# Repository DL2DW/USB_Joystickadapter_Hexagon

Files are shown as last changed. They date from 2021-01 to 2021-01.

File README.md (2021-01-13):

# USB Joystickadapter from Hexagon (SMD Version)

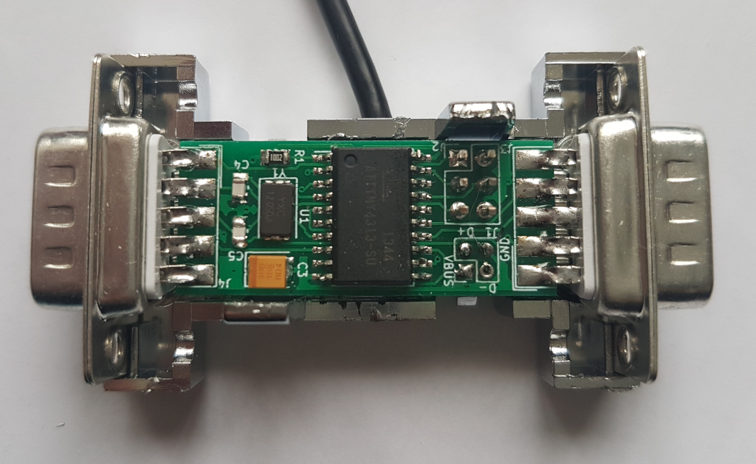
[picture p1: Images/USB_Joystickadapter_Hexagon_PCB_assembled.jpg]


I found the documentation and firmware for this joystick adapter on the website http://www.hexagons.de/index.php/USB_Joystickadapter some time ago. This is no longer available online for a long time.

It is a joystick adapter with 2 ports for the known DB9 connectors, as they are used with the Atari, or Commodore joysticks. 

This adapter can be connected to a PC or the well known MiSTer FPGA hardware, and so the old homecomputer joysticks can be used on modern hardware.

## "Sinchai" version

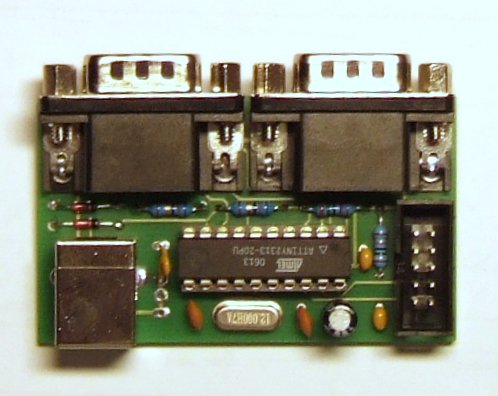
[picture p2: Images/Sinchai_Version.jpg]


There is also a version that is built with normal THT components. This was once sold in a store, but it no longer exists.

And I could not find a suitable case for Hexagon's version. So I packed the hardware into an existing case with the help of a newly developed circuit board.

## Assembly

Under the article number "COM 943" there is a housing at the electronics mail order company Reichelt from Germany ( https://www.reichelt.de/selbstbaugehaeuse-d-sub-2x-9-pol-metallisiert-com-943-p161.html?&nbc=1 ), in which two 9pin D-SUB sockets fit wonderfully. You only have to drill a small hole for the USB cable.

The board is equipped with SMD components to save space. Whereby I have worked here with parts as large as possible, so that on SMD beginners could assemble this board without problems.

The assembly is actually quite simple, since only a few components are needed. The components are assembled from small to large. First the resistors, then the capacitors, followed by the quartz. Then the programmable microcontroller.

Finally the pin header, which is needed to program the microcontroller and the two DB9 connectors. Here I recommend to put the construction together first by hand and to solder it into one half of the case. Then solder the first side of the DB9 sockets to the board. And then the back side can be soldered.

Then a small hole must be drilled in a bottom part of the adapter in the side, so that the USB cable can be put through there. It is best to take a ready-made cable with an open end. Such cables are available at Reichelt.

After passing the cable through the previously drilled hole, the wires can be soldered to the board. To secure the cable from being pulled out, a small cable tie should be pulled around the cable.

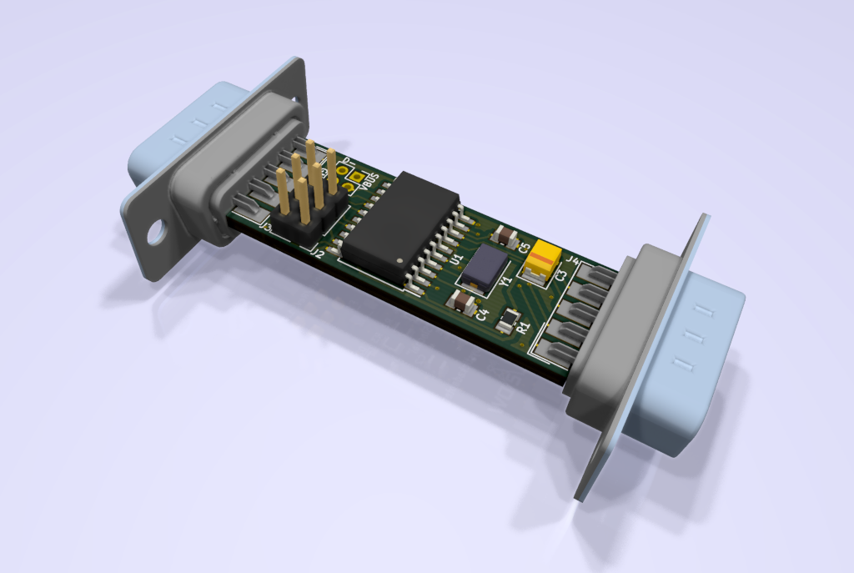
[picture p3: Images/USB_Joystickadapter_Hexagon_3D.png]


When everything is assembled, the adapter should look like this.

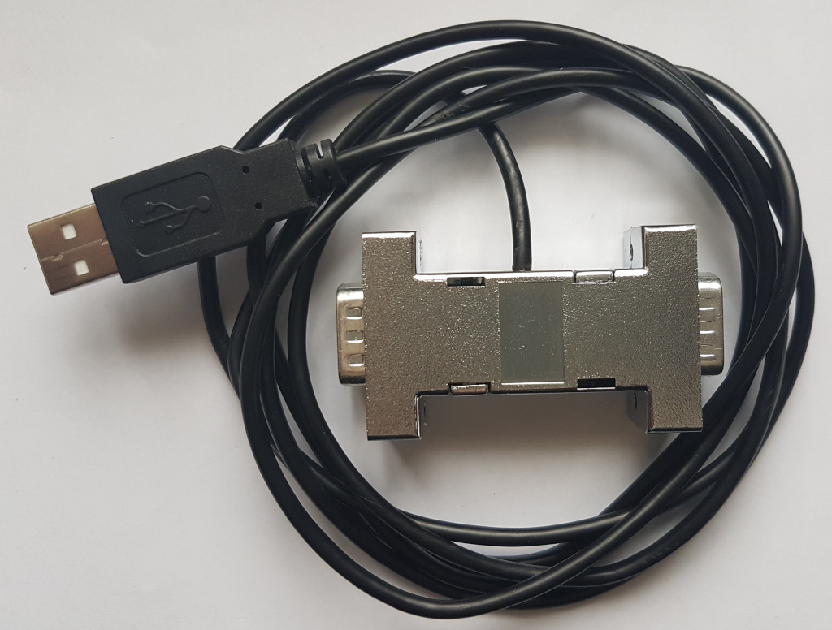
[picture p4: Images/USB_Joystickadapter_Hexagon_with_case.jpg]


## Flashing the firmware

Now only the microcontroller must be flashed with the appropriate firmware. This can be done most simply with the tool avrdude. The call differs of course, depending on the used programming adapter a little bit. For the very popular and widely used USBASP adapter the whole thing would look like this:

**avrdude -c usbasp -p t4313 -U flash:w:main4313.hex -U lfuse:w:0xcf:m -U hfuse:w:0xdb:m -U efuse:w:0xff:m** 

## BOM

Here is the list of components. 

- 2x 100nF capacitor / 0805
- 1x 10µF tantalum capacitor / Kemet B
- 2x 22pF capacitor / 0805
- 2x Zener diode BZT52C3V6 / SOD 123
- 1x Littlefuse1206L150THWR / 1206
- 2x DB9 female, male with solder cups
- 1x 10k resistor 1/8W, 1% / 0805
- 1x 1.5k resistor 1/8W, 1% / 0805 
- 2x 68 resistor 1/8W, 1% / 0805 
- 1x ATTiny 4313-SU / SOIC-20W
- 1x 12MHZ crystal / 5032, 2pin
- header 2 rows
- USB connection cable

## PCB

The PCB can either be ordered directly from [PCBWay](https://www.pcbway.com/project/shareproject/USB_Joystickadapter_from_Hexagon__SMD_Version_.html), or you can create it yourself from the Gerber files available here.

PCBWay (https://www.pcbway.com/project/shareproject/USB_Joystickadapter_from_Hexagon__SMD_Version_.html)

If you liked my project, I would be very happy about a small coffee donation.



# License

The contents of this repository, with the exception of the Firmware directory, are released under the following license:

- the "Creative Commons Attribution-NonCommercial-ShareAlike 4.0 International License" (CC BY-NC-SA 4.0) full text of this license is included in the [LICENSE.CC-NC-BY-SA-4.0](https://github.com/DL2DW/TriMod_Adapter_SMD_Version/blob/main/LICENSE.CC-NC-BY-SA) file and a copy can also be found at https://creativecommons.org/licenses/by-nc-sa/4.0/

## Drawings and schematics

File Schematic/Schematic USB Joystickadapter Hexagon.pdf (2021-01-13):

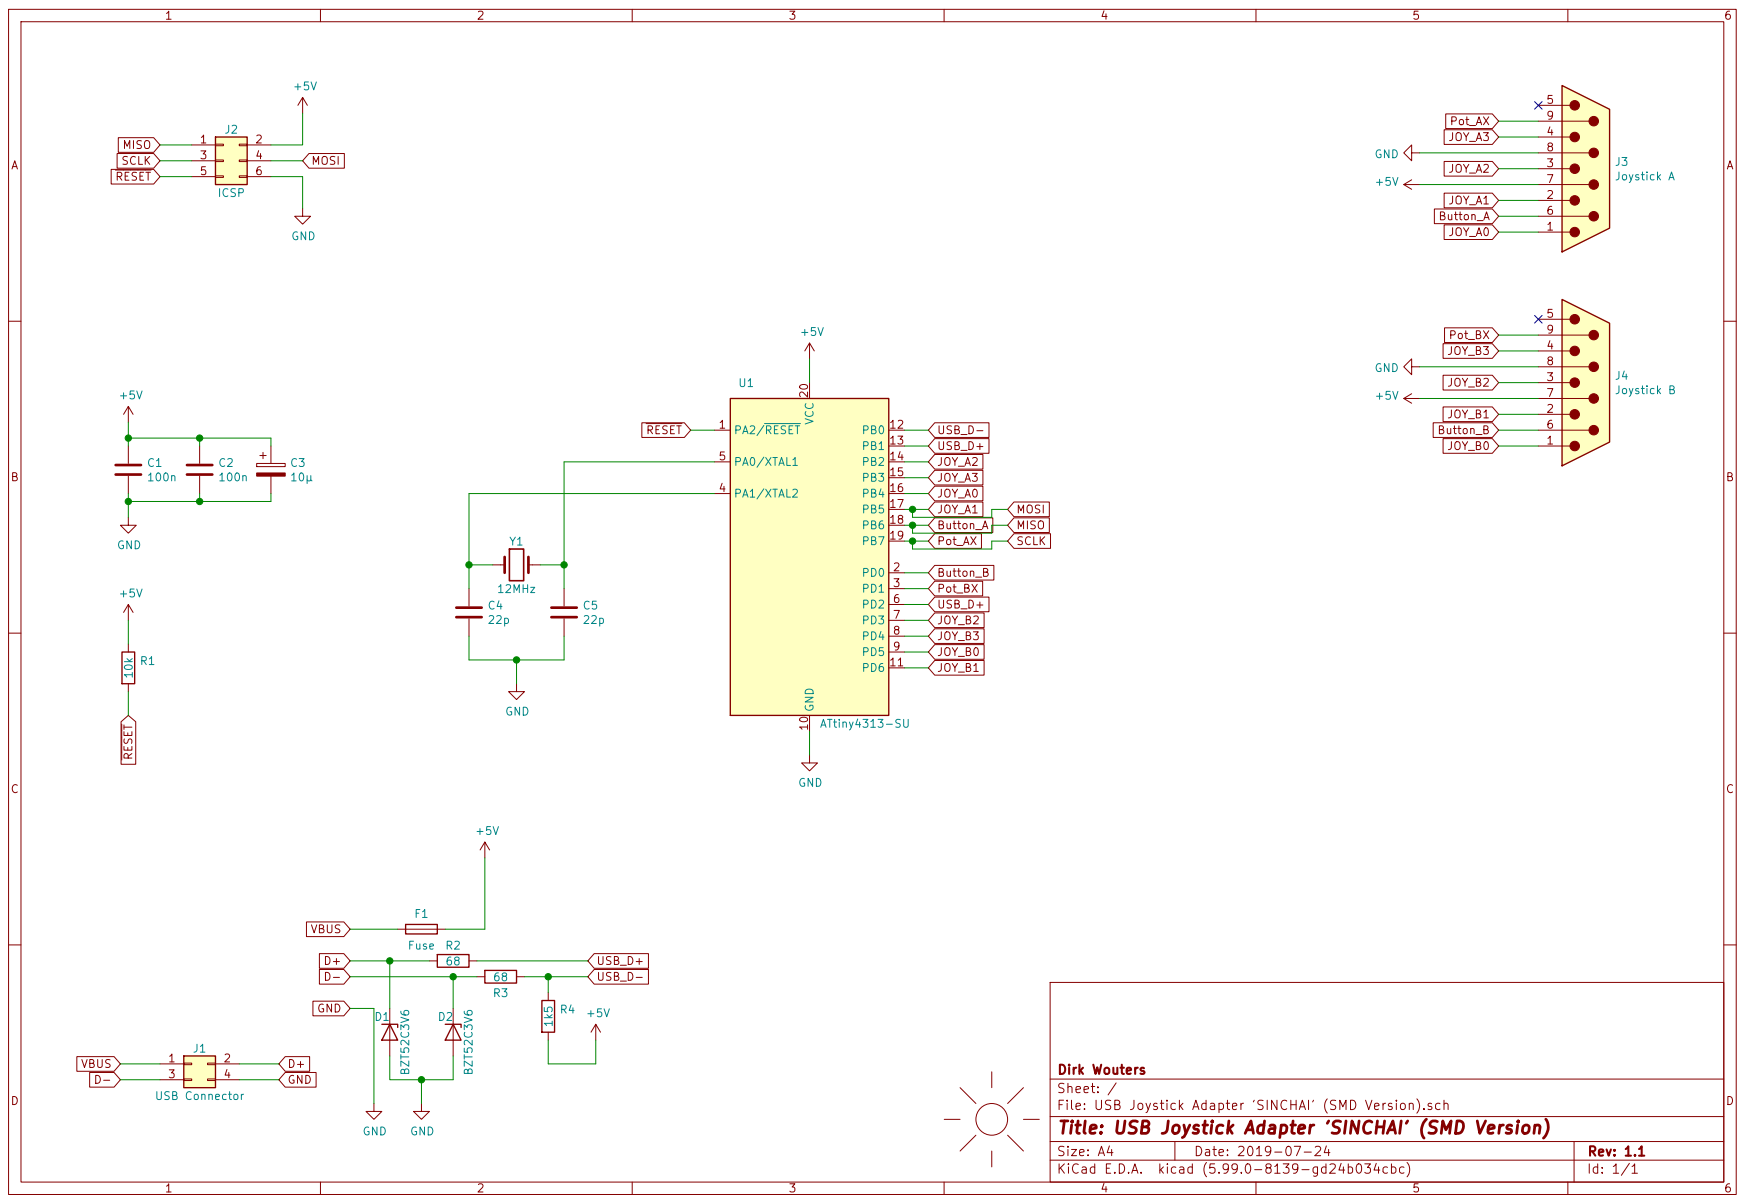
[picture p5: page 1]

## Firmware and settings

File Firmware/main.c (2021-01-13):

/*
 * USB-Joystickadapter Firmware
 *    
 * based on project hid-mouse, a very simple HID example by Christian Starkjohann, OBJECTIVE DEVELOPMENT Software GmbH
 * and ATtiny2313 USB Joyadapter firmware by Grigori Goronzy.    
 * adapted for ATtiny4313, changes for ATtiny2313 with new compiler by Andreas Paul 05/2011
 * complete rewrite by Philipp Lang 01/2015
 * 
 * Name: main.c
 * Project: USB-Joystickadapter
 * Author: Andreas Paul, Philipp Lang (Christian Starkjohann, Grigori Goronzy) 
 * Creation Date: 2015-01-31
 * 
 * License: GNU GPL v2 (see License.txt), GNU GPL v3 or proprietary (CommercialLicense.txt)
 * This Revision: $Id: $
 */

/*
  Wiring             | Port | 7    6    5    4    3    2    1    0    |
  -------------------+------+-----------------------------------------+
  Left joystick      | PB   | But2 But1 Down Up   Rght Left -    -    |
  Right Joystick     | PD   | -    Down Up   Rght Left -    But2 But1 |
*/

#include <avr/io.h>
#include <avr/wdt.h>
#include <avr/interrupt.h>
#include <avr/eeprom.h>
#include <util/delay.h>
#include "usbdrv.h"

/* USB configuration descriptor */
PROGMEM const char usbDescriptorConfiguration[] = {
  9,          /* sizeof(usbDescriptorConfiguration): length of descriptor in bytes */
  USBDESCR_CONFIG,    /* descriptor type */
  9 + (2*(9+9+7)), 0, /* total length of data returned (including inlined descriptors) */
  2,          /* number of interfaces in this configuration */
  1,          /* index of this configuration */
  0,          /* configuration name string index */
#if USB_CFG_IS_SELF_POWERED
  (1 << 7) | USBATTR_SELFPOWER,       /* attributes */
#else
  (1 << 7),                           /* attributes */
#endif
  USB_CFG_MAX_BUS_POWER/2,            /* max USB current in 2mA units */

/* interface 1 descriptor follows inline: */
  9,          /* sizeof(usbDescrInterface): length of descriptor in bytes */
  USBDESCR_INTERFACE, /* descriptor type */
  0,          /* index of this interface */
  0,          /* alternate setting for this interface */
  1,          /* endpoints excl 0: number of endpoint descriptors to follow */
  USB_CFG_INTERFACE_CLASS,
  USB_CFG_INTERFACE_SUBCLASS,
  USB_CFG_INTERFACE_PROTOCOL,
  3,          /* string index for interface */
  9,          /* sizeof(usbDescrHID): length of descriptor in bytes */
  USBDESCR_HID,   /* descriptor type: HID */
  0x01, 0x01, /* BCD representation of HID version */
  0x00,       /* target country code */
  0x01,       /* number of HID Report (or other HID class) Descriptor infos to follow */
  0x22,       /* descriptor type: report */
  USB_CFG_HID_REPORT_DESCRIPTOR_LENGTH, 0,  /* total length of report descriptor */

/* endpoint descriptor for endpoint 1 */
  7,          /* sizeof(usbDescrEndpoint) */
  USBDESCR_ENDPOINT,  /* descriptor type = endpoint */
  (char)0x81, /* IN endpoint number 1 */
  0x03,       /* attrib: Interrupt endpoint */
  8, 0,       /* maximum packet size */
  USB_CFG_INTR_POLL_INTERVAL, /* in ms */

/* interface 2 descriptor follows inline: */
  9,          /* sizeof(usbDescrInterface): length of descriptor in bytes */
  USBDESCR_INTERFACE, /* descriptor type */
  1,          /* index of this interface */
  0,          /* alternate setting for this interface */
  1,          /* endpoints excl 0: number of endpoint descriptors to follow */
  USB_CFG_INTERFACE_CLASS,
  USB_CFG_INTERFACE_SUBCLASS,
  USB_CFG_INTERFACE_PROTOCOL,
  4,          /* string index for interface */
  9,          /* sizeof(usbDescrHID): length of descriptor in bytes */
  USBDESCR_HID,   /* descriptor type: HID */
  0x01, 0x01, /* BCD representation of HID version */
  0x00,       /* target country code */
  0x01,       /* number of HID Report (or other HID class) Descriptor infos to follow */
  0x22,       /* descriptor type: report */
  USB_CFG_HID_REPORT_DESCRIPTOR_LENGTH, 0,  /* total length of report descriptor */

/* endpoint descriptor for endpoint 3 */
  7,          /* sizeof(usbDescrEndpoint) */
  USBDESCR_ENDPOINT,  /* descriptor type = endpoint */
  (char)(0x80 | USB_CFG_EP3_NUMBER), /* IN endpoint number 3 */
  0x03,       /* attrib: Interrupt endpoint */
  8, 0,       /* maximum packet size */
  USB_CFG_INTR_POLL_INTERVAL, /* in ms */
};

PROGMEM const char usbHidReportDescriptor[42] = {
  0x05, 0x01,   // USAGE_PAGE (Generic Desktop)
  0x09, 0x04,   // USAGE (Joystick)
  0xa1, 0x01,   // COLLECTION (Application)
  0x09, 0x01,   //   USAGE (Pointer)
  0xa1, 0x00,   //   COLLECTION (Physical)
  0x09, 0x30,   //     USAGE (X)
  0x09, 0x31,   //     USAGE (Y)
  0x15, 0xff,   //     LOGICAL_MINIMUM (-1)
  0x25, 0x01,   //     LOGICAL_MAXIMUM (1)
  0x75, 0x03,   //     REPORT_SIZE (3)
  0x95, 0x02,   //     REPORT_COUNT (2)
  0x81, 0x02,   //     INPUT (Data,Var,Abs)
  0xc0,         //   END_COLLECTION
  0x05, 0x09,   //   USAGE_PAGE (Button)
  0x19, 0x01,   //   USAGE_MINIMUM (Button 1)
  0x29, 0x02,   //   USAGE_MAXIMUM (Button 2)
  0x15, 0x00,   //   LOGICAL_MINIMUM (0)
  0x25, 0x01,   //   LOGICAL_MAXIMUM (1)
  0x75, 0x01,   //   REPORT_SIZE (1)
  0x95, 0x02,   //   REPORT_COUNT (2)
  0x81, 0x02,   //   INPUT (Data,Var,Abs)
  0xc0,         // END_COLLECTION
};

static uchar ReportBuffer[2] = { 0x02, 0x02 }; // initialize with impossible values
static uchar IdleRate = 0; // infinite
static const char Desc0Str[] = { 4, 3, 0x09, 0x04 };
static PROGMEM const char VendorStr[]   = "hexagons.de";
static PROGMEM const char JoystickStr[] = "Retro-Joystick #x";

usbMsgLen_t usbFunctionDescriptor(struct usbRequest *rq)
{
  static char buf[(sizeof(JoystickStr) > sizeof(VendorStr) ? sizeof(JoystickStr) : sizeof(VendorStr))*2];

  uchar ix = rq->wValue.bytes[0];
  const char* s;
  uchar l;
  uchar ifchar = 0;
  if (ix == 0) { // String0
    usbMsgPtr = (usbMsgPtr_t)Desc0Str;
    return 4;
  }
  else if (ix == 1) { // Vendor
    s = VendorStr;
    l = sizeof(VendorStr) * 2;
  }
  else if (ix == 2) { // Product
    s = JoystickStr;
    l = (sizeof(JoystickStr) - 3) * 2;
  }
  else if (ix == 3 || ix == 4) { // Interface 1 or 2
    s = JoystickStr;
    l = sizeof(JoystickStr) * 2;
    ifchar = '1' + ix - 3;
  }
  else {
    return 0;
  }
  
  // copy from ROM to RAM with char to wchar conversion
  char* d = buf + 2;
  char c;
  while ((c = pgm_read_byte(s++)) != 0) {
    *d = c;
    d += 2;
  }
  
  buf[0] = l; // length
  buf[1] = 3; // string descriptor mark
  if (ifchar)
    buf[(sizeof(JoystickStr)-1) * 2] = ifchar; // patch interface number
  usbMsgPtr = (usbMsgPtr_t)buf;
  return l;
}

usbMsgLen_t usbFunctionSetup(uchar data[8])
{
  usbRequest_t *rq = (void *)data;
  if ((rq->bmRequestType & USBRQ_TYPE_MASK) == USBRQ_TYPE_CLASS) {
    // class request type
    switch (rq->bRequest) {
    case USBRQ_HID_GET_REPORT:
      // wValue: ReportType, ReportID
      // wIndex: interface
      usbMsgPtr = &ReportBuffer[rq->wIndex.word & 1];
      return 1;
    case USBRQ_HID_GET_IDLE:
      usbMsgPtr = &IdleRate;
      return 1;
    case USBRQ_HID_SET_IDLE:
      // ignore
      return 0;
    }
  }
  return 0;
}

static uchar encodeReport(uchar pin)
{
  pin = ~pin;
  uchar r = pin & 0xc0; // buttons
  if (pin & _BV(5)) // down
    r |= 0x08;
  if (pin & _BV(4)) // up
    r |= 0x38;
  if (pin & _BV(3)) // right
    r |= 0x01;
  if (pin & _BV(2)) // left
    r |= 0x07;
  return r;
}

int __attribute__((noreturn)) main(void)
{
  // reset status: port bits are inputs without pull-up.
  // enable pull-up on joystick pins, keep D+/D-
  PORTB = 0xfc;
  PORTD = 0x7b;
  wdt_enable(WDTO_1S);
  
  // enforce re-enumeration, do this while interrupts are disabled!
  // fake USB disconnect for > 250 ms
  usbInit();
  usbDeviceDisconnect();
  uchar i = 0;
  while (--i)
    _delay_ms(1);
  
  // the port mapping can be selected by holding the left joystick while plugging-in the adapter:
  // button1 + left: left joystick will be reported as joystick #1
  // button1 + right: right joystick will be reported as joystick #1
  // the mapping is stored in the eeprom
  uchar swapPorts = eeprom_read_byte((uint8_t *)0);
  uchar newSwapPorts = swapPorts;
  i = PINB & 0x7c;
  if (i == 0x38) // button1 + left => no swap
    newSwapPorts = 0;
  else if (i == 0x34) // button1 + right => swap
    newSwapPorts = 1;
  if (newSwapPorts != swapPorts) {
    eeprom_write_byte((uint8_t *)0, newSwapPorts);
    while ((PINB & 0xfc) != 0xfc) // wait until joystick is back in null position (indicates success to user)
      wdt_reset();
  }
  
  usbDeviceConnect();
  sei();

  // main loop
  for (;;) {
    wdt_reset();

    usbPoll();
    
    uchar r1 = encodeReport(PINB);
    uchar x = PIND & 0x7b;
    uchar r2 = encodeReport((x >> 1) | (x << 6));
    if (swapPorts) {
      x = r1;
      r1 = r2;
      r2 = x;
    }

    if (ReportBuffer[0] != r1) {
      ReportBuffer[0] = r1;
      usbSetInterrupt(&ReportBuffer[0], 1);
    }
    if (ReportBuffer[1] != r2) {
      ReportBuffer[1] = r2;
      usbSetInterrupt3(&ReportBuffer[1], 1);
    }
  }
}
